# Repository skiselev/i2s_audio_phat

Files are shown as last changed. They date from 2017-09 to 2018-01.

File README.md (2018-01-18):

# I2S Audio pHAT
I2S Audio Interface for Raspberry Pi Zero

## Introduction
This is a Raspberry Pi Zero pHAT form-factor I2S audio interface board based on a [Cirrus Logic (Wolfson) WM8731](https://www.cirrus.com/products/wm8731/) audio codec. It provides line input, line output, headphones output, and includes an on-board microphone.

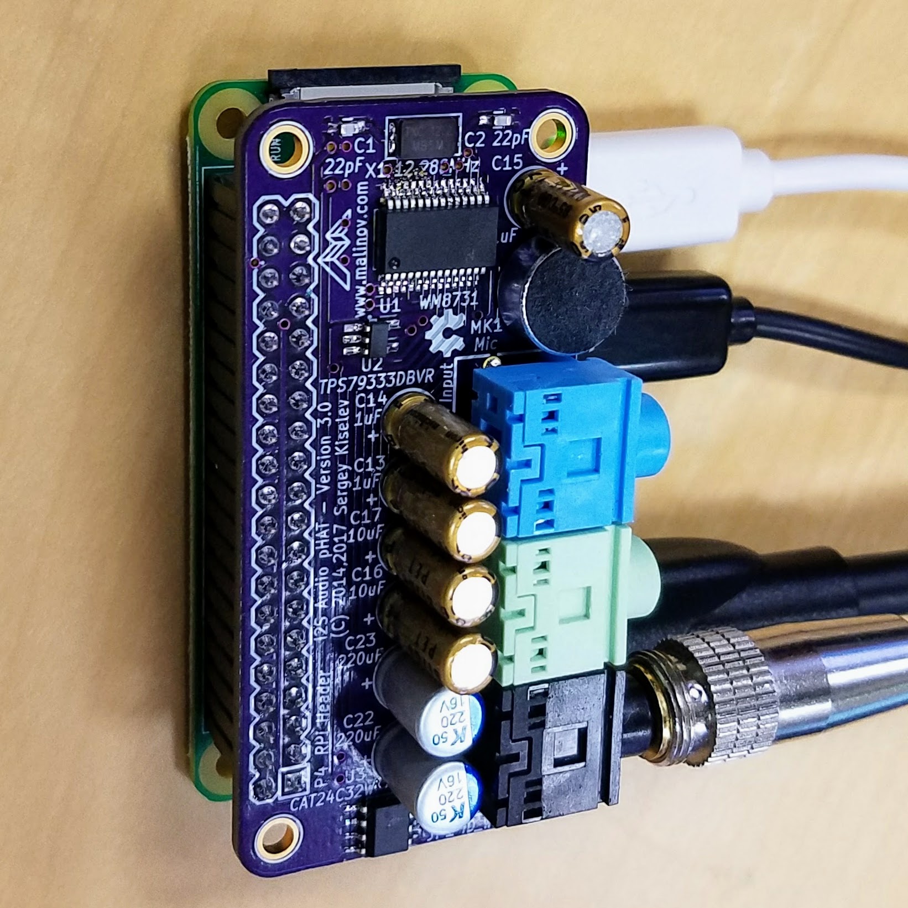
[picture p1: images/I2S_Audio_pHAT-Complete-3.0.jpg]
Micro 8088 Assembled Board


## Hardware Documentation

### Schematic and PCB Layout

[Schematic - Version 3.0](documentation/I2S_Audio_pHAT-Schematic-3.0.pdf)

[PCB Layout - Version 3.0](documentation/I2S_Audio_pHAT-Board-3.0.pdf)

### Bill of Materials

[I2S Audio pHAT project on Mouser.com](https://www.mouser.com/ProjectManager/ProjectDetail.aspx?AccessID=6262cdf84a) - View and order all components except of the PCB.

[I2S Audio pHAT project on OSH Park](https://oshpark.com/shared_projects/yxrgLBxI) - View and order the PCB.

Component type     | Reference | Description                       | Quantity | Possible sources and notes 
------------------ | --------- | --------------------------------- | -------- | --------------------------
PCB                |           | I2S Audio pHAT PCB - Version 3.0  | 1        | Order from [OSH Park](https://oshpark.com/shared_projects/yxrgLBxI)
Integrated Circuit | U1        | WM8731, I2S audio codec, SSOP28   | 1        | Mouser [238-WM8731SEDS/V](https://www.mouser.com/ProductDetail/238-WM8731SEDS-V)
Integrated Circuit | U2        | TPS79333DBVR, LDO, SOT23-5        | 1        | Mouser [595-TPS79333DBVR](https://www.mouser.com/ProductDetail/595-TPS79333DBVR)
Integrated Circuit | U3        | CAT24C32WI-GT3, I2C EEPROM, SOIC8 | 1        | Mouser [698-CAT24C32WI-GT3](https://www.mouser.com/ProductDetail/698-CAT24C32WI-GT3)
Crystal            | X1        | 12.288MHz, 3 mm x 5.3 mm          | 1        | Mouser [717-7A-12.288MAAJ-T](https://www.mouser.com/ProductDetail/717-7A-12288MAAJ-T)
Microphone         | MK1       | 9.7 mm, electret condenser microphone | 1        | Mouser [490-CMA-4544PF-W](https://www.mouser.com/ProductDetail/490-CMA-4544PF-W)
Connector          | P1        | 3.5 mm audio jack, blue           | 1        | Mouser [806-STX-31205B284C](https://www.mouser.com/ProductDetail/806-STX-31205B284C)
Connector          | P2        | 3.5 mm audio jack, green          | 1        | Mouser [806-STX-31205B577C](https://www.mouser.com/ProductDetail/806-STX-31205B577C)
Connector          | P3        | 3.5 mm audio jack, black          | 1        | Mouser [806-STX-3120-5B](https://www.mouser.com/ProductDetail/806-STX-3120-5B)
Connector          | P4        | 20x2, 2.54 mm, socket             | 1        | Mouser [517-929852-01-20-RB](https://www.mouser.com/ProductDetail/517-929852-01-20-RB)
Header             | JP1       | 2x1, 2.54mm, header               | 1        | (optional) Mouser [855-M20-9990245](https://www.mouser.com/ProductDetail/855-M20-9990245)
Capacitor          | C1, C2    | 22pF, 0603                        | 2        | Mouser [77-VJ0603A220JXACBC](https://www.mouser.com/ProductDetail/77-VJ0603A220JXACBC)
Capacitor          | C3-C5     | 220pF, 0603                       | 3        | Mouser [77-VJ0603A221GXAPBC](https://www.mouser.com/ProductDetail/77-VJ0603A221GXAPBC)
Capacitor          | C6        | 0.01uF, 0603                      | 1        | Mouser [77-VJ0603Y103KXACBC](https://www.mouser.com/ProductDetail/77-VJ0603Y103KXACBC)
Capacitor          | C7-C12    | 0.1uF, 0603                       | 6        | Mouser [77-VJ0603Y104JXJPBC](https://www.mouser.com/ProductDetail/77-VJ0603Y104JXJPBC)
Capacitor          | C13-C15   | 1uF, 5 mm, radial                 | 3        | Mouser [647-USW1H010MDD](https://www.mouser.com/ProductDetail/647-USW1H010MDD)
Capacitor          | C16, C17  | 10uF, 5 mm, radial                | 2        | Mouser [647-USW1H100MDD](https://www.mouser.com/ProductDetail/647-USW1H100MDD)
Capacitor          | C18-C21   | 10uF, 0603                        | 4        | Mouser [81-GRM188R61A106KE9D](https://www.mouser.com/ProductDetail/81-GRM188R61A106KE9D)
Capacitor          | C22, C23  | 220uF, 6.3 mm, radial             | 2        | Mouser [647-USW0J221MDD](https://www.mouser.com/ProductDetail/647-USW0J221MDD)
Resistor           | R1-R6     | 33 ohm, 0603                      | 6        | Mouser [603-RC0603FR-0733RL](https://www.mouser.com/ProductDetail/603-RC0603FR-0733RL)
Resistor           | R7, R8    | 100 ohm, 0603                     | 2        | Mouser [603-RC0603FR-07100RL](https://www.mouser.com/ProductDetail/603-RC0603FR-07100RL)
Resistor           | R9        | 330 ohm, 0603                     | 1        | Mouser [603-RC0603FR-07330RL](https://www.mouser.com/ProductDetail/603-RC0603FR-07330RL)
Resistor           | R10       | 680 ohm, 0603                     | 1        | Mouser [603-RC0603FR-07680RL](https://www.mouser.com/ProductDetail/603-RC0603FR-07680RL)
Resistor           | R11       | 1 kohm, 0603                      | 1        | Mouser [603-RC0603FR-071KL](https://www.mouser.com/ProductDetail/603-RC0603FR-071KL)
Resistor           | R12, R13  | 3.9 kohm, 0603                    | 2        | Mouser [603-RC0603FR-073K9L](https://www.mouser.com/ProductDetail/603-RC0603FR-073K9L)
Resistor           | R14-R18   | 5.6 kohm, 0603                    | 5        | Mouser [603-RC0603FR-075K6L](https://www.mouser.com/ProductDetail/603-RC0603FR-075K6L)
Resistor           | R19-R22   | 47 kohm, 0603                     | 4        | Mouser [603-RC0603FR-0747KL](https://www.mouser.com/ProductDetail/603-RC0603FR-0747KL)

## Software Documentation

### Raspbian Configuration

Open `/boot/config.txt` in your favorite editor (nano, vi) as root, for example:

    sudo nano /boot/config.txt

Comment out the `dtparam=audio=on` line:

    # Enable audio (loads snd_bcm2835)
    #dtparam=audio=on

When using I2S Audio pHAT _without_ ID EEPROM (see [Raspberry Pi HAT ID EEPROM Programming](#raspberry-pi-hat-id-eeprom-programming) section below), add the following lines:

    # Enable WM8731 codec
    dtparam=i2c_arm=on
    dtparam=i2s=on
    dtoverlay=i2s-mmap
    dtoverlay=rpi-proto

Save the file and reboot the system.

Start `alsamixer`. If the I2S Audio pHAT is detected properly, it should show _Card: snd_rpi_proto_ on the top left. Also use this opportunity to unmute *Output Mixer HiFi* control, otherwise the codec will not play any sound. To do so, use cursor keys to highlight that control, and then press the *M* key to unmute it.

When recording the sound, switch to *Capture* controls in `alsamixer` by pressing the *F4* key. Next select the capture source: *Line* or *Mic*, and unmute it by pressing the *Space* key.

Now you can use your favorite application to play music or record sound. Enjoy!

### Raspberry Pi HAT ID EEPROM Programming

The I2S Audio pHAT includes an ID EEPROM as specified by HAT requirements. This ID EEPROM allows Raspbian to automatically detect the I2S Audio pHAT, add it to the device tree, and load approprate overlays and kernel modules. Follow the instructions below to program the EEPROM.

Clone the Raspberry Pi [hats](https://github.com/raspberrypi/hats) repostory from GitHub:

    git clone https://github.com/raspberrypi/hats

Clone the [I2S Audio pHAT](https://github.com/skiselev/i2s_audio_phat) repository from GitHub:

    git clone https://github.com/skiselev/i2s_audio_phat

Build the `eepromutils` in the `hats` repository:

    cd hats/eepromutils
    make

Create the `i2s_audio_phat.eep` ID EEPROM image, using the `eeprom_settings_i2s_audio_phat.txt` file provided in the `i2s_audio_phat` repository:

    ./eepmake ../../i2s_audio_phat/eeprom_settings_i2s_audio_phat.txt i2s_audio_phat.eep /boot/overlays/rpi-proto.dtbo

Finally, flash the `i2s_audio_phat.eep` ID EEPROM image to the EEPROM. Make sure to close the JP1 jumper on the I2S Audio pHAT before writing the EEPROM, for example using male to male jumper wire, or otherwise the write will fail.

    sudo ./eepflash.sh -w -f=i2s_audio_phat.eep -t=24c32

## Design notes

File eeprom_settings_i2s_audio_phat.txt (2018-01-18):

########################################################################
# EEPROM settings text file
#
# Edit this file for your particular board and run through eepmake tool,
# then use eepflash tool to write to attached HAT ID EEPROM 
#
# Tools available:
#  eepmake   Parses EEPROM text file and creates binary .eep file
#  eepdump   Dumps a binary .eep file as human readable text (for debug)
#  eepflash  Write or read .eep binary image to/from HAT EEPROM
#
########################################################################

########################################################################
# Vendor info

# 128 bit UUID. If left at zero eepmake tool will auto-generate
# RFC 4122 compliant UUID
product_uuid 96a92d15-ea9e-4d4d-9404-353c440b9b29

# 16 bit product id
product_id 0x0001

# 16 bit product version
product_ver 0x0030

# ASCII vendor string  (max 255 characters)
vendor "Sergey Kiselev"

# ASCII product string (max 255 characters)
product "I2S Audio pHAT"

########################################################################
# GPIO bank settings, set to nonzero to change from the default.
# NOTE these setting can only be set per BANK, uncommenting any of
# these will force the bank to use the custom setting.

# drive strength, 0=default, 1-8=2,4,6,8,10,12,14,16mA, 9-15=reserved
gpio_drive 0

# 0=default, 1=slew rate limiting, 2=no slew limiting, 3=reserved
gpio_slew 0

# 0=default, 1=hysteresis disabled, 2=hysteresis enabled, 3=reserved
gpio_hysteresis 0

# If board back-powers Pi via 5V GPIO header pins:
# 0 = board does not back-power
# 1 = board back-powers and can supply the Pi with a minimum of 1.3A
# 2 = board back-powers and can supply the Pi with a minimum of 2A
# 3 = reserved
# If back_power=2 then USB high current mode will be automatically 
# enabled on the Pi
back_power 0

########################################################################
# GPIO pins, uncomment for GPIOs used on board
# Options for FUNCTION: INPUT, OUTPUT, ALT0-ALT5
# Options for PULL: DEFAULT, UP, DOWN, NONE
# NB GPIO0 and GPIO1 are reserved for ID EEPROM so cannot be set

#         GPIO  FUNCTION  PULL
#         ----  --------  ----
#setgpio  2     INPUT     DEFAULT
#setgpio  3     INPUT     DEFAULT
#setgpio  4     INPUT     DEFAULT
#setgpio  5     INPUT     DEFAULT
#setgpio  6     INPUT     DEFAULT
#setgpio  7     INPUT     DEFAULT
#setgpio  8     INPUT     DEFAULT
#setgpio  9     INPUT     DEFAULT
#setgpio  10    INPUT     DEFAULT
#setgpio  11    INPUT     DEFAULT
#setgpio  12    INPUT     DEFAULT
#setgpio  13    INPUT     DEFAULT
#setgpio  14    INPUT     DEFAULT
#setgpio  15    INPUT     DEFAULT
#setgpio  16    INPUT     DEFAULT
#setgpio  17    INPUT     DEFAULT
#setgpio  18    INPUT     DEFAULT
#setgpio  19    INPUT     DEFAULT
#setgpio  20    INPUT     DEFAULT
#setgpio  21    INPUT     DEFAULT
#setgpio  22    INPUT     DEFAULT
#setgpio  23    INPUT     DEFAULT
#setgpio  24    INPUT     DEFAULT
#setgpio  25    INPUT     DEFAULT
#setgpio  26    INPUT     DEFAULT
#setgpio  27    INPUT     DEFAULT

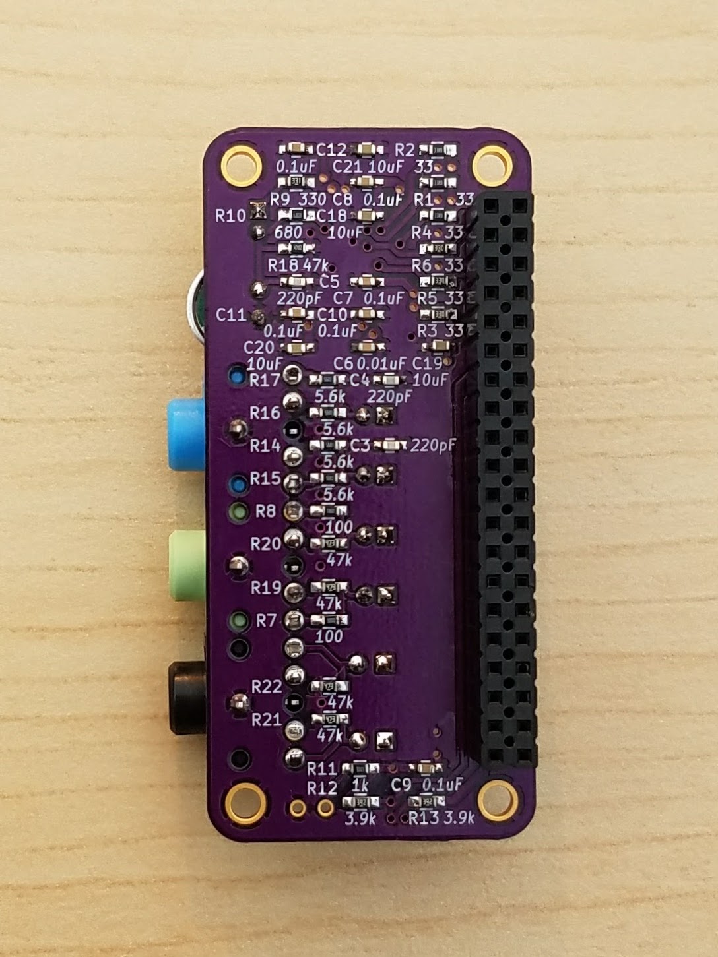
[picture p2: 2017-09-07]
images/I2S_Audio_pHAT-Bottom-3.0.jpg

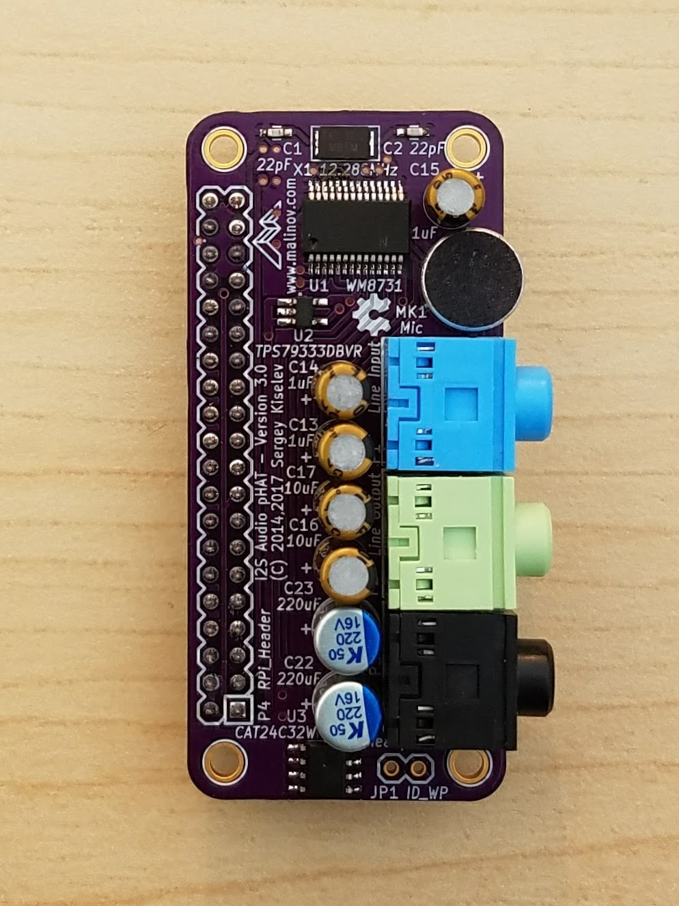
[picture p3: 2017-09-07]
images/I2S_Audio_pHAT-Top-3.0.jpg

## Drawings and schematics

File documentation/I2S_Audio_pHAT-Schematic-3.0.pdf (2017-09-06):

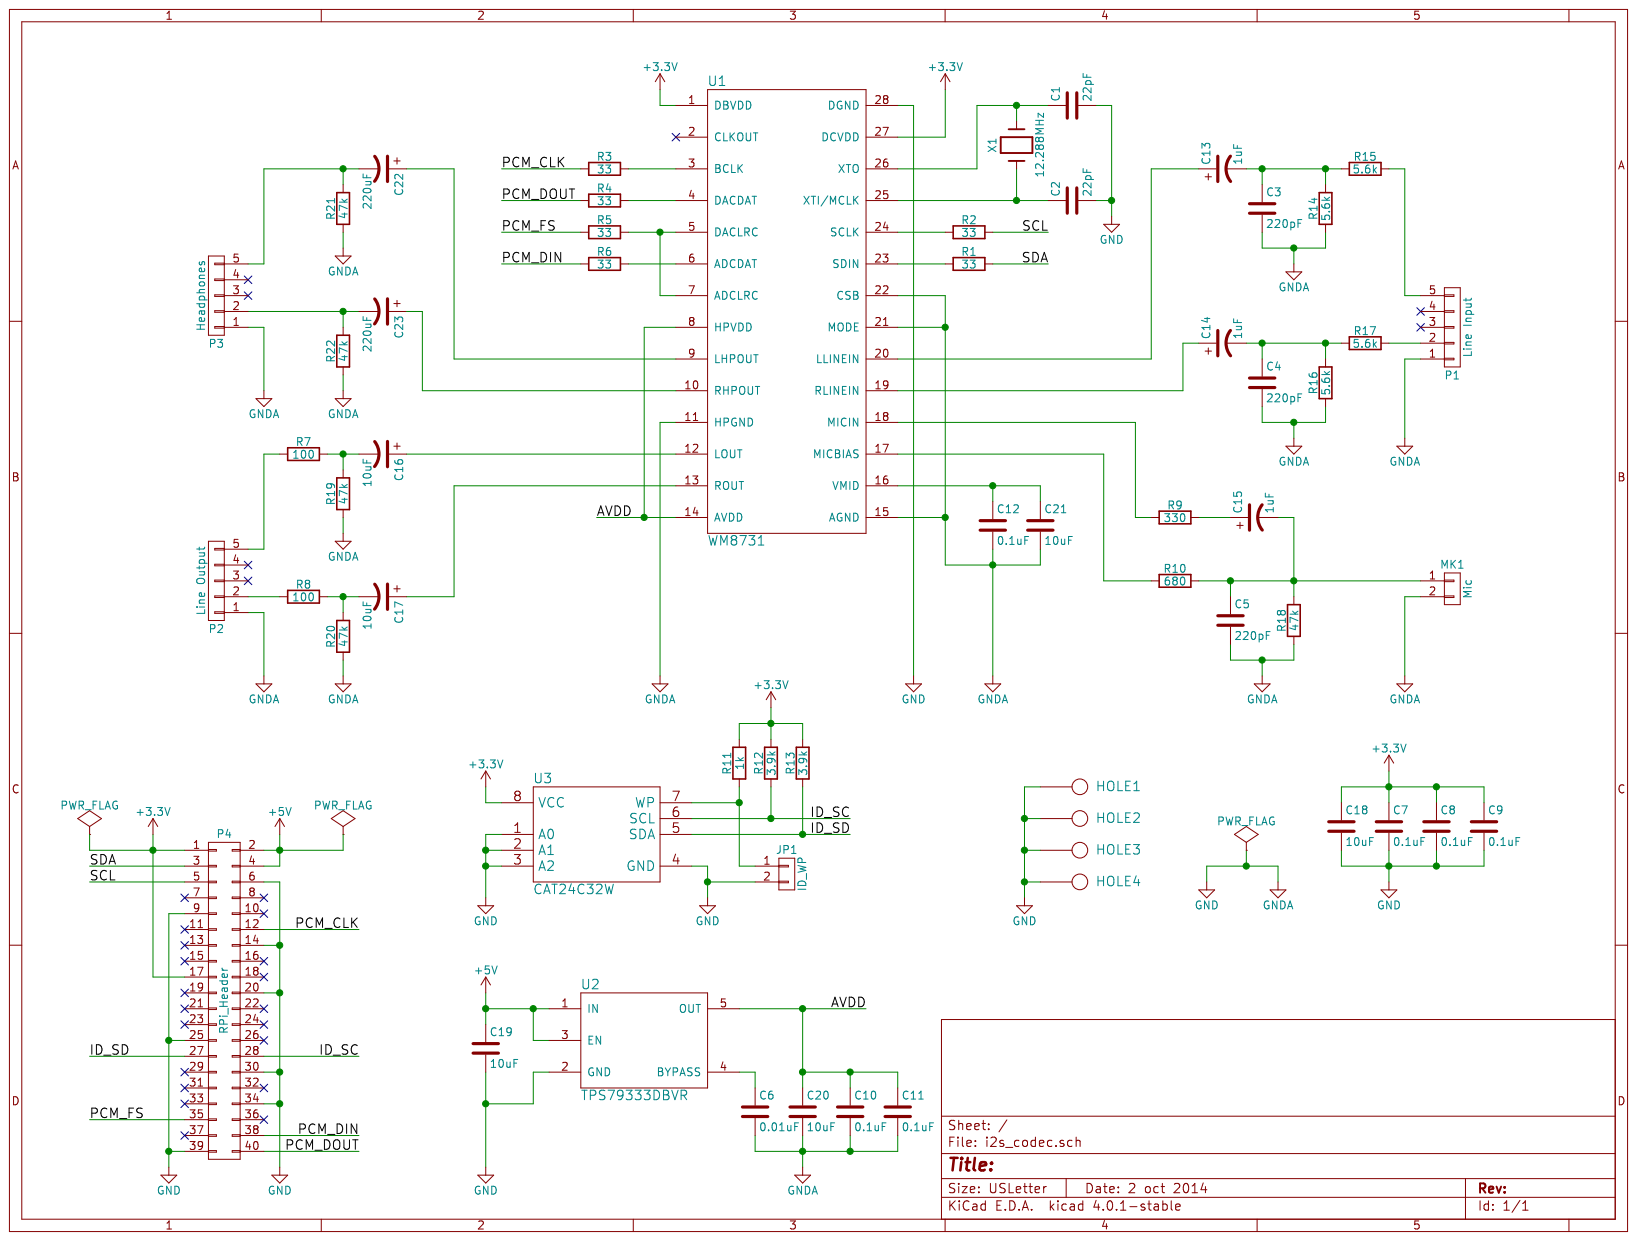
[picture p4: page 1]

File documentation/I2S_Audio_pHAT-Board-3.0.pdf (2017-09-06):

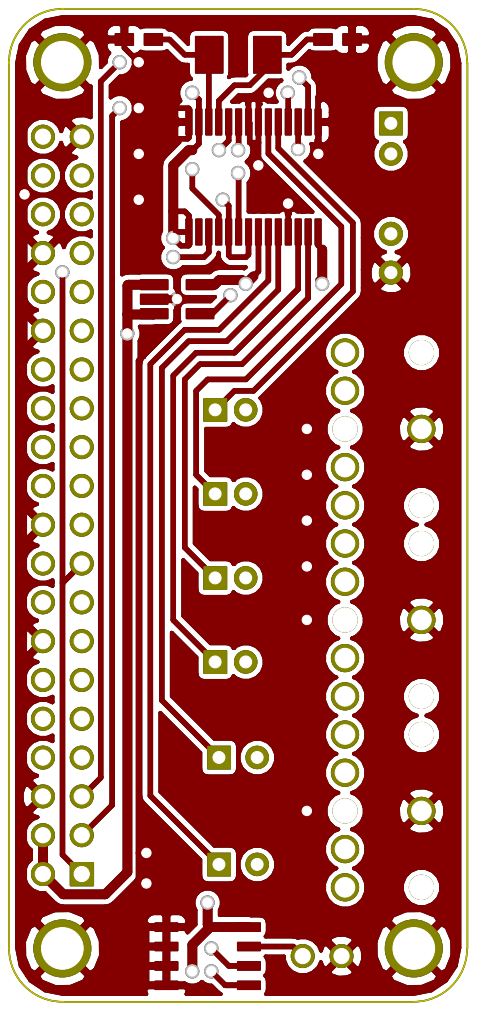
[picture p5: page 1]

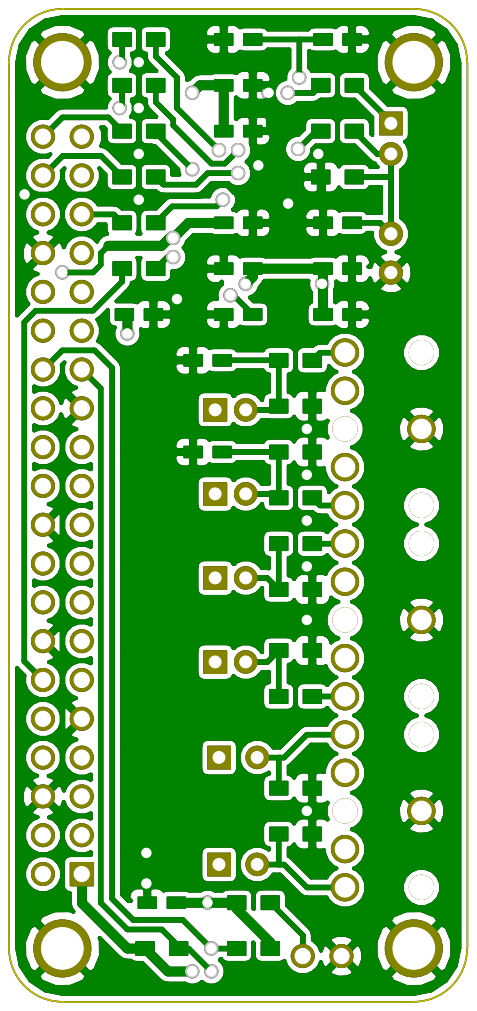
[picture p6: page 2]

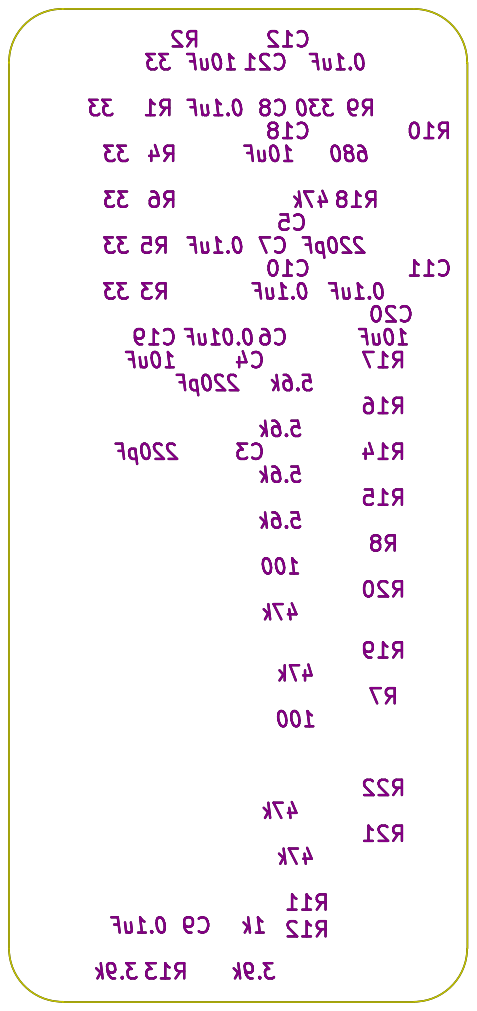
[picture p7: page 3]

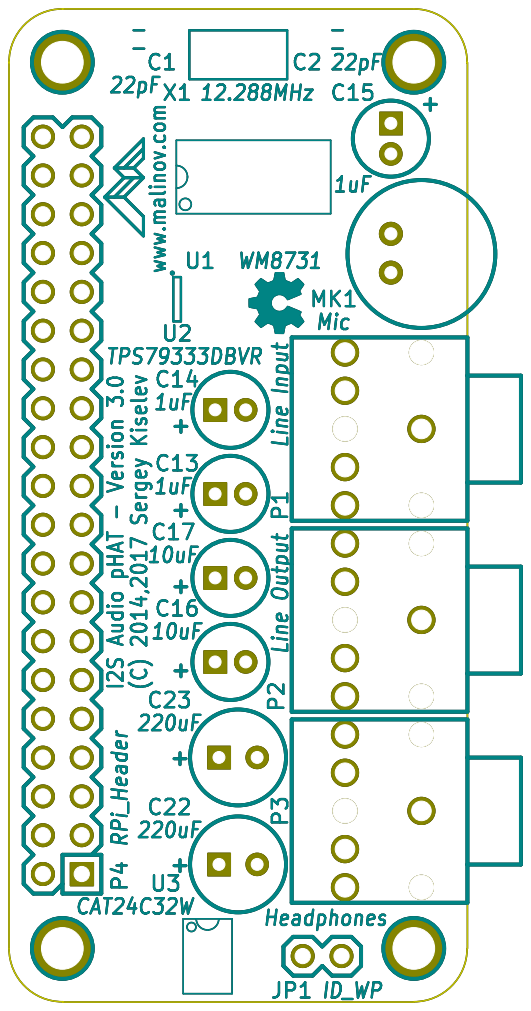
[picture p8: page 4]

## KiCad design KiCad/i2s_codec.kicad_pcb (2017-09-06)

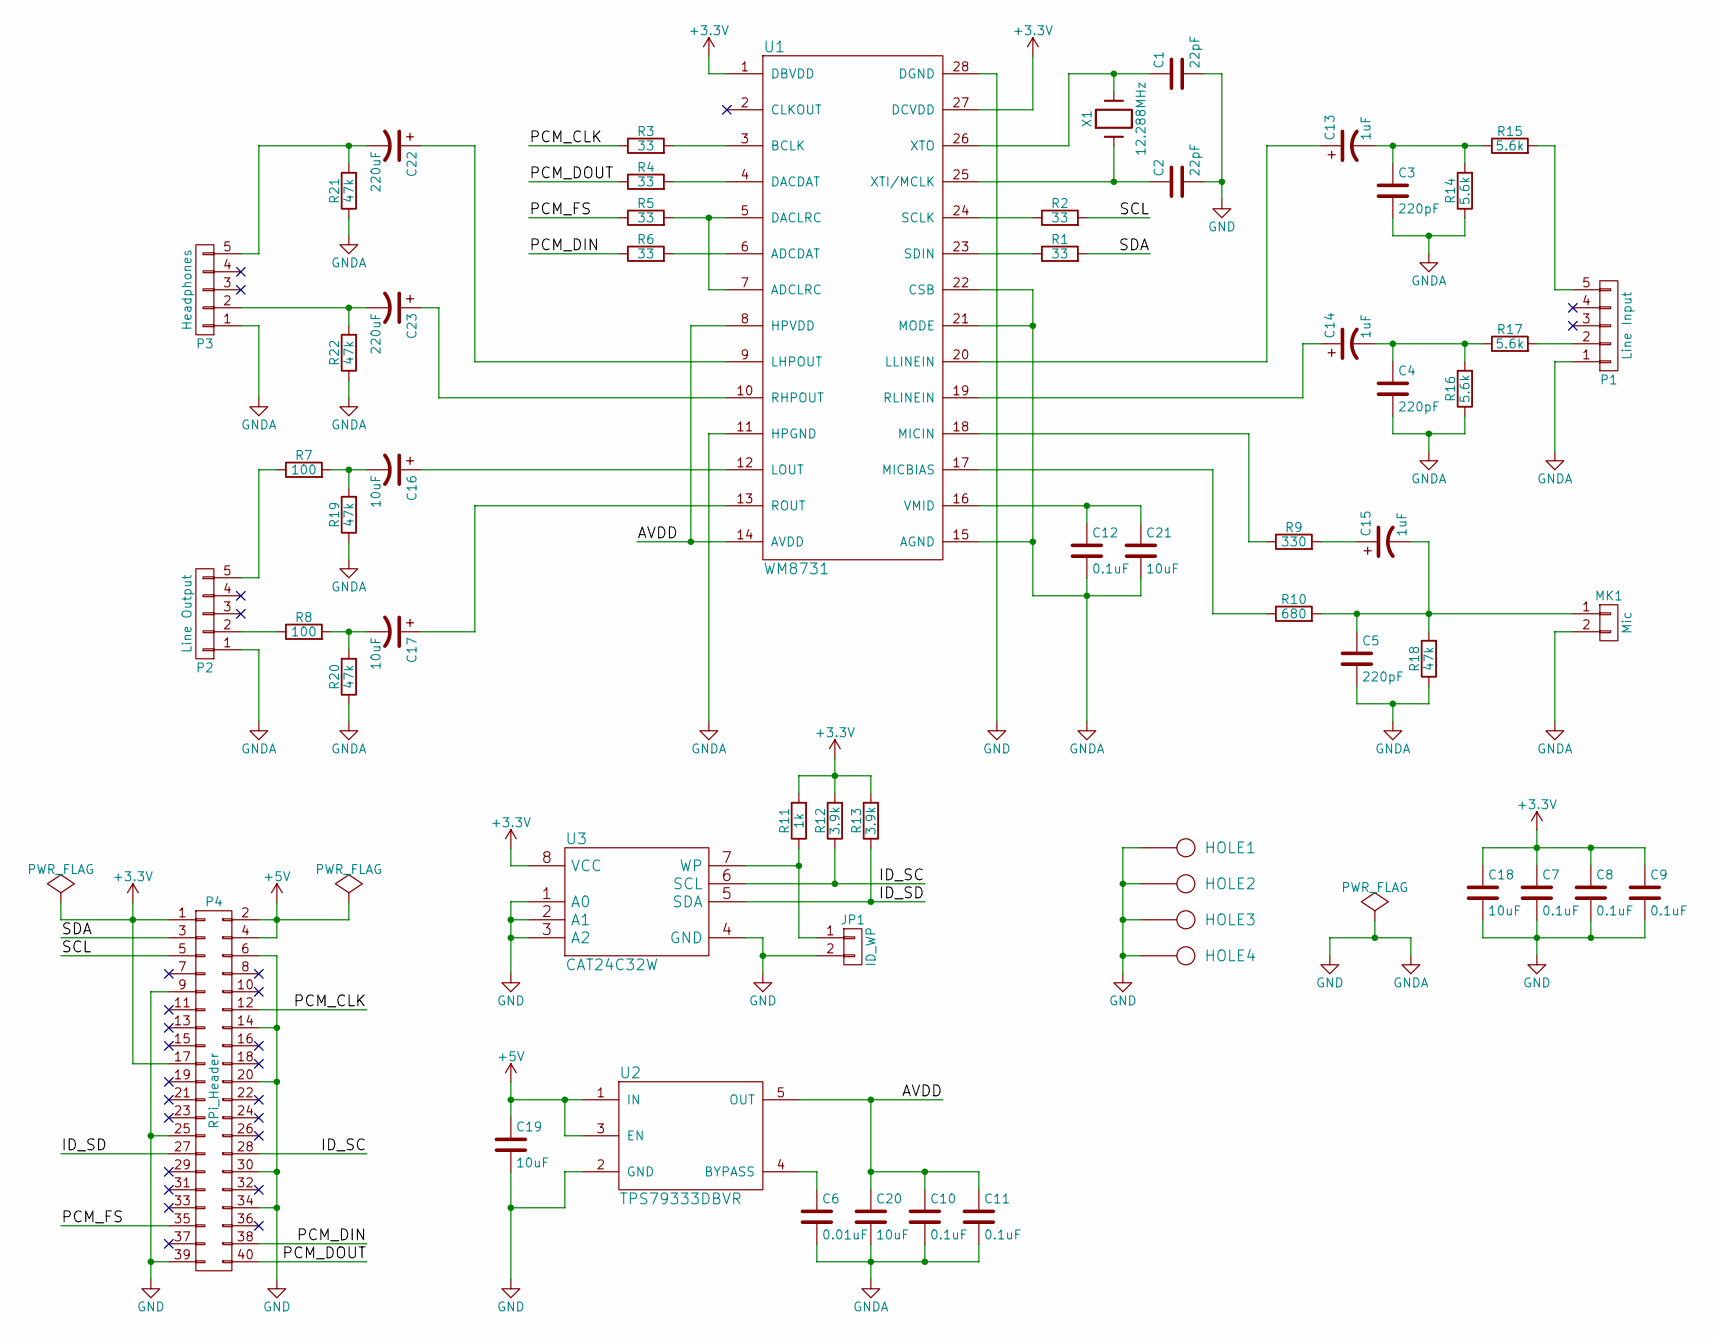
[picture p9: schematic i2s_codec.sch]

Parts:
C1, C2: 22pF; C_0603_HandSoldering
C3, C4, C5: 220pF; C_0603_HandSoldering
C6: 0.01uF; C_0603_HandSoldering
C7, C8, C9, C10, C11, C12: 0.1uF; C_0603_HandSoldering
C13, C14, C15: 1uF; Cap_Elec_Radial_5mm
C16, C17: 10uF; Cap_Elec_Radial_5mm
C18, C19, C20, C21: 10uF; C_0603_HandSoldering
C22, C23: 220uF; Cap_Elec_Radial_6.3mm
HOLE1, HOLE2, HOLE3, HOLE4: HOLE; Hole_2.75mm
JP1: ID_WP; Conn_Pin_Header_2x1_2.54mm_NoKey
MK1: Mic; Microphone
P1: Line Input; Conn_Audio_3.5mm_Stereo
P2: Line Output; Conn_Audio_3.5mm_Stereo
P3: Headphones; Conn_Audio_3.5mm_Stereo
P4: RPi_Header; Conn_Pin_Header_20x2_2.54mm
R1, R2, R3, R4, R5, R6: 33; R_0603_HandSoldering
R7, R8: 100; R_0603_HandSoldering
R9: 330; R_0603_HandSoldering
R10: 680; R_0603_HandSoldering
R11: 1k; R_0603_HandSoldering
R12, R13: 3.9k; R_0603_HandSoldering
R14, R15, R16, R17: 5.6k; R_0603_HandSoldering
R18, R19, R20, R21, R22: 47k; R_0603_HandSoldering
U1: WM8731; IC_SSOP28
U2: TPS79333DBVR; IC_SOT23-5_Hand_Soldering
U3: CAT24C32W; IC_SOIC8_Narrow
X1: 12.288MHz; Crystal_5.0x3.2mm

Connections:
+3V3: C7.1, C8.1, C9.1, C18.1, P4.1, P4.17, R11.2, R12.2, R13.2, U1.1 (DBVDD), U1.27 (DCVDD), U3.8 (VCC)
+5V: C19.1, P4.2, P4.4, U2.1 (IN), U2.3 (EN)
/AVDD: C10.1, C11.1, C20.1, U1.8 (HPVDD), U1.14 (AVDD), U2.5 (OUT)
/ID_SC: P4.28, R12.1, U3.6 (SCL)
/ID_SD: P4.27, R13.1, U3.5 (SDA)
/PCM_CLK: P4.12, R3.1
/PCM_DIN: P4.38, R6.1
/PCM_DOUT: P4.40, R4.1
/PCM_FS: P4.35, R5.1
/SCL: P4.5, R2.2
/SDA: P4.3, R1.2
GND: C1.2, C2.2, C3.2, C4.2, C5.2, C6.2, C7.2, C8.2, C9.2, C10.2, C11.2, C12.2, C18.2, C19.2, C20.2, C21.2, HOLE1.1, HOLE2.1, HOLE3.1, HOLE4.1, JP1.2, MK1.2, P1.1, P2.1, P3.1, P4.6, P4.9, P4.14, P4.20, P4.25, P4.30, P4.34, P4.39, R14.1, R16.1, R18.1, R19.1, R20.1, R21.1, R22.1, U1.11 (HPGND), U1.15 (AGND), U1.21 (MODE), U1.22 (CSB), U1.28 (DGND), U2.2 (GND), U3.1 (A0), U3.2 (A1), U3.3 (A2), U3.4 (GND)
unnamed: C1.1, U1.26 (XTO), X1.2
unnamed: C2.1, U1.25 (XTI/MCLK), X1.1
unnamed: C6.1, U2.4 (BYPASS)
unnamed: C12.1, C21.1, U1.16 (VMID)
unnamed: C13.1, U1.20 (LLINEIN)
unnamed: C3.1, C13.2, R14.2, R15.1
unnamed: C14.1, U1.19 (RLINEIN)
unnamed: C4.1, C14.2, R16.2, R17.1
unnamed: C15.1, R9.2
unnamed: C5.1, C15.2, MK1.1, R10.2, R18.2
unnamed: C16.1, U1.12 (LOUT)
unnamed: C16.2, R7.2, R19.2
unnamed: C17.1, U1.13 (ROUT)
unnamed: C17.2, R8.2, R20.2
unnamed: C22.1, U1.9 (LHPOUT)
unnamed: C22.2, P3.5, R21.2
unnamed: C23.1, U1.10 (RHPOUT)
unnamed: C23.2, P3.2, R22.2
unnamed: JP1.1, R11.1, U3.7 (WP)
unnamed: P1.2, R17.2
unnamed: P1.5, R15.2
unnamed: P2.2, R8.1
unnamed: P2.5, R7.1
unnamed: R1.1, U1.23 (SDIN)
unnamed: R2.1, U1.24 (SCLK)
unnamed: R3.2, U1.3 (BCLK)
unnamed: R4.2, U1.4 (DACDAT)
unnamed: R5.2, U1.5 (DACLRC), U1.7 (ADCLRC)
unnamed: R6.2, U1.6 (ADCDAT)
unnamed: R9.1, U1.18 (MICIN)
unnamed: R10.1, U1.17 (MICBIAS)

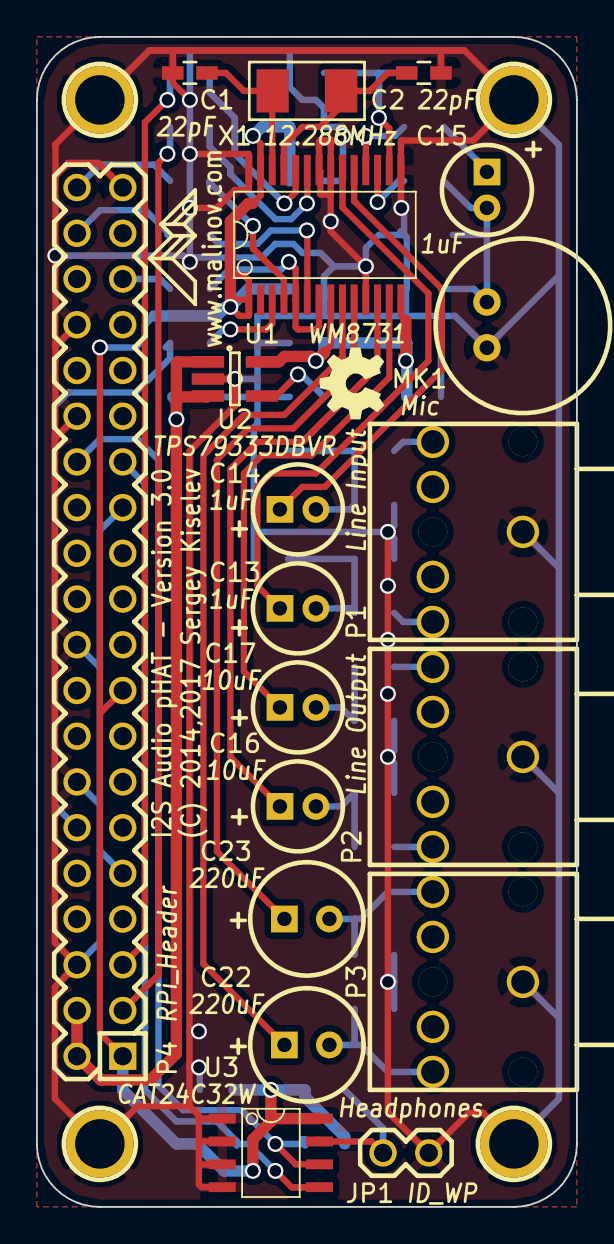
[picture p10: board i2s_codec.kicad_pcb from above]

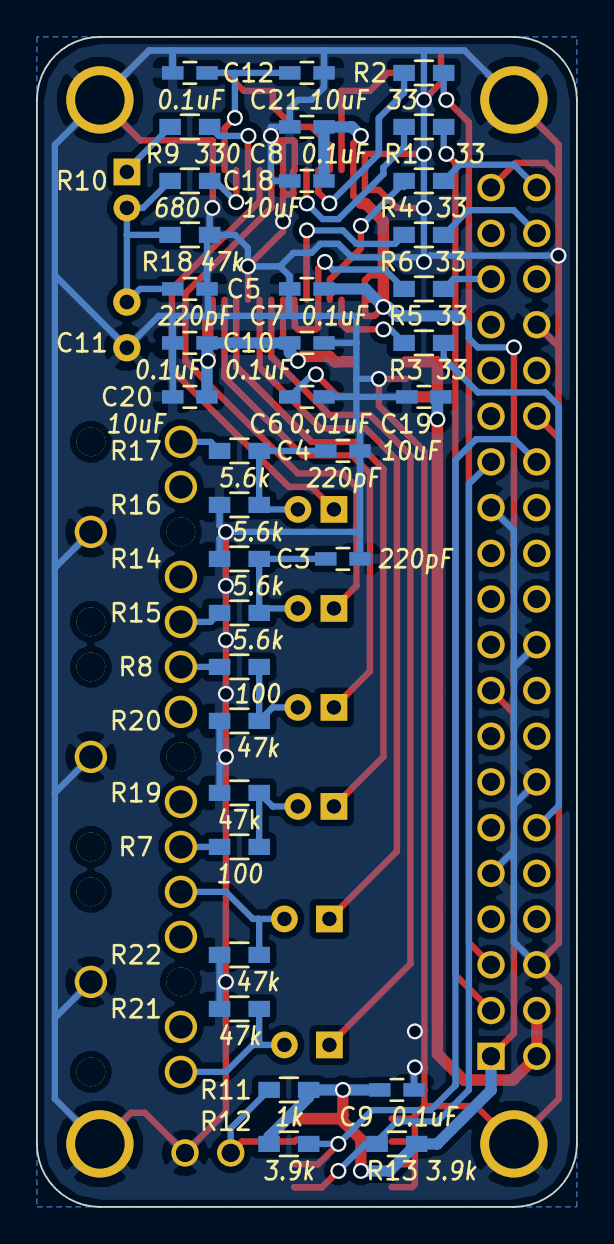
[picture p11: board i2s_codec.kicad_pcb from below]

Board: 2 copper layers, 30.0 x 65.0 mm, 59 parts (36 on the bottom side), 43 nets.

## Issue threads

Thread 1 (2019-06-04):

No sound

dmckminard, 2019-06-04:
Hello !
I mounted the phat i2s audio card, and I have some concerns. It is correctly recognized by debian, but impossible to have sound. Do you know where it can come from?
I am on debian stretch.

skiselev, 2019-06-04:
Hi,

It is possible that the mixer is muted. In this case the WM8731 won't even accept the data for the playback. Please check the mixer settings, unmute if needed.
I think the following commands should do it:
`amixer set 'Master' 80 unmute`
`amixer set 'Output Mixer HiFi' unmute`

 If that still doesn't work, please send me the output of `amixer contents`

Thanks!

dmckminard, 2019-06-05:
I've done this and still no sound.

Please see below the output of amixer contents:

> numid=2,iface=MIXER,name='Master Playback ZC Switch'
  ; type=BOOLEAN,access=rw------,values=2
  : values=off,off
numid=1,iface=MIXER,name='Master Playback Volume'
  ; type=INTEGER,access=rw---R--,values=2,min=0,max=127,step=0
  : values=127,127
  | dBscale-min=-121.00dB,step=1.00dB,mute=1
numid=4,iface=MIXER,name='Line Capture Switch'
  ; type=BOOLEAN,access=rw------,values=2
  : values=off,off
numid=5,iface=MIXER,name='Mic Boost Volume'
  ; type=INTEGER,access=rw---R--,values=1,min=0,max=1,step=0
  : values=0
  | dBscale-min=0.00dB,step=20.00dB,mute=0
numid=6,iface=MIXER,name='Mic Capture Switch'
  ; type=BOOLEAN,access=rw------,values=1
  : values=off
numid=8,iface=MIXER,name='ADC High Pass Filter Switch'
  ; type=BOOLEAN,access=rw------,values=1
  : values=on
numid=3,iface=MIXER,name='Capture Volume'
  ; type=INTEGER,access=rw---R--,values=2,min=0,max=31,step=0
  : values=31,31
  | dBscale-min=-34.50dB,step=1.50dB,mute=0
numid=10,iface=MIXER,name='Playback Deemphasis Switch'
  ; type=BOOLEAN,access=rw------,values=1
  : values=off
numid=14,iface=MIXER,name='Input Mux'
  ; type=ENUMERATED,access=rw------,values=1,items=2
  ; Item #0 'Line In'
  ; Item #1 'Mic'
  : values=0
numid=13,iface=MIXER,name='Output Mixer HiFi Playback Switch'
  ; type=BOOLEAN,access=rw------,values=1
  : values=on
numid=11,iface=MIXER,name='Output Mixer Line Bypass Switch'
  ; type=BOOLEAN,access=rw------,values=1
  : values=off
numid=12,iface=MIXER,name='Output Mixer Mic Sidetone Switch'
  ; type=BOOLEAN,access=rw------,values=1
  : values=off
numid=7,iface=MIXER,name='Sidetone Playback Volume'
  ; type=INTEGER,access=rw---R--,values=1,min=0,max=3,step=0
  : values=3
  | dBscale-min=-15.00dB,step=3.00dB,mute=0
numid=9,iface=MIXER,name='Store DC Offset Switch'
  ; type=BOOLEAN,access=rw------,values=1
  : values=off

Thanks to you for your reply!

skiselev, 2019-06-05:
The mixer settings look good to me. My only other guess would be that the sound is being output elsewhere, for example to the built-in RPi BCM audio.
Can you please provide the output of
`aplay -l`
And also the command you're using to play the audio.
I'll try to reproduce the issue locally. It might take some time though.

skiselev, 2019-06-10:
I've tested my pHAT with the current release of Raspbian Stretch, dated 2019-04-08, and it works just fine.
I'd recommend checking the LHPOUT (#9) and RHPOUT (#10) output pins on WM8731 with an oscilloscope. Or checking that coupling capacitors C22 and C23 are connected correctly.
You might also want to check the signal on Line Output jack.

dmckminard, 2019-06-11:
Ok I'm going to check that so. But I have some doubts about the fact that it comes from an electronic problem on my side, because I developed 2 cards like yours and neither of them works.
Just to be sure, you can configure the card via the Raspbian Configuration part, or via the Raspberry Pi HAT ID EEPROM Programming part. The latter is not essential, and I can very well only go through the steps described in Raspbian Configuration?

skiselev, 2019-06-11:
Can you please try removing or commenting out the following line from your /boot/config.txt:
`dtoverlay=i2s-mmap`
It seems that it is not needed on Raspbian Stretch.

dmckminard, 2019-06-17:
Oh sorry I've forget to answer! No still no sound

skiselev, 2019-06-18:
Weird. Do you have an oscilloscope to check the I2S signals and audio output signals?

dmckminard, 2019-07-03:
Yes, all seems good

dmckminard, 2019-07-04:
Yes, you were right! My problems comes from hardware. I've baked a new card and it's working nice, thanks !

Closed 2019-07-04.

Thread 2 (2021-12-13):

missing my_components

hemna, 2021-12-13:
Do you happen to have the 'my_components' library?

I'm trying to use your repo as a basis for building a cm4 carrier board that will use this audio schematic and kicad is complaining about missing my_components library.   I'm on macos btw.

skiselev, 2021-12-13:
It should be here: https://github.com/skiselev/my_kicad_library, although that library is pretty much work in progress, so it might not match whatever is in the I2S Audio pHAT

Closed 2021-12-14.

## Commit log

2017-09-06 Initial drop
    [i2s_codec.kicad_pcb, i2s_codec.sch]
2018-01-18 README.md: Update BoM: Audio electrolytic capacitors; shorter Mouser URLs

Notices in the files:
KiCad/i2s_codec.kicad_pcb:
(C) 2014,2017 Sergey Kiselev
